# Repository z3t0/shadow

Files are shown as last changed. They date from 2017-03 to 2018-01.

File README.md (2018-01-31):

# SumoDuino 

SumoDuino

### What is this repository for?
**Project Name: SumoDuino**

**Project Summary: AVR based project using to create a SumoBot**

**Version: 1.1**

### Features
* Seek and find navigation system
* Line-Sensing logic to keep robot in the ring
* Several InfraRed sensors to allow accurate seeking

### Credits
Rafi Khan, I am the owner and main contributor to this repository.
Email: zetoslab@gmail.com

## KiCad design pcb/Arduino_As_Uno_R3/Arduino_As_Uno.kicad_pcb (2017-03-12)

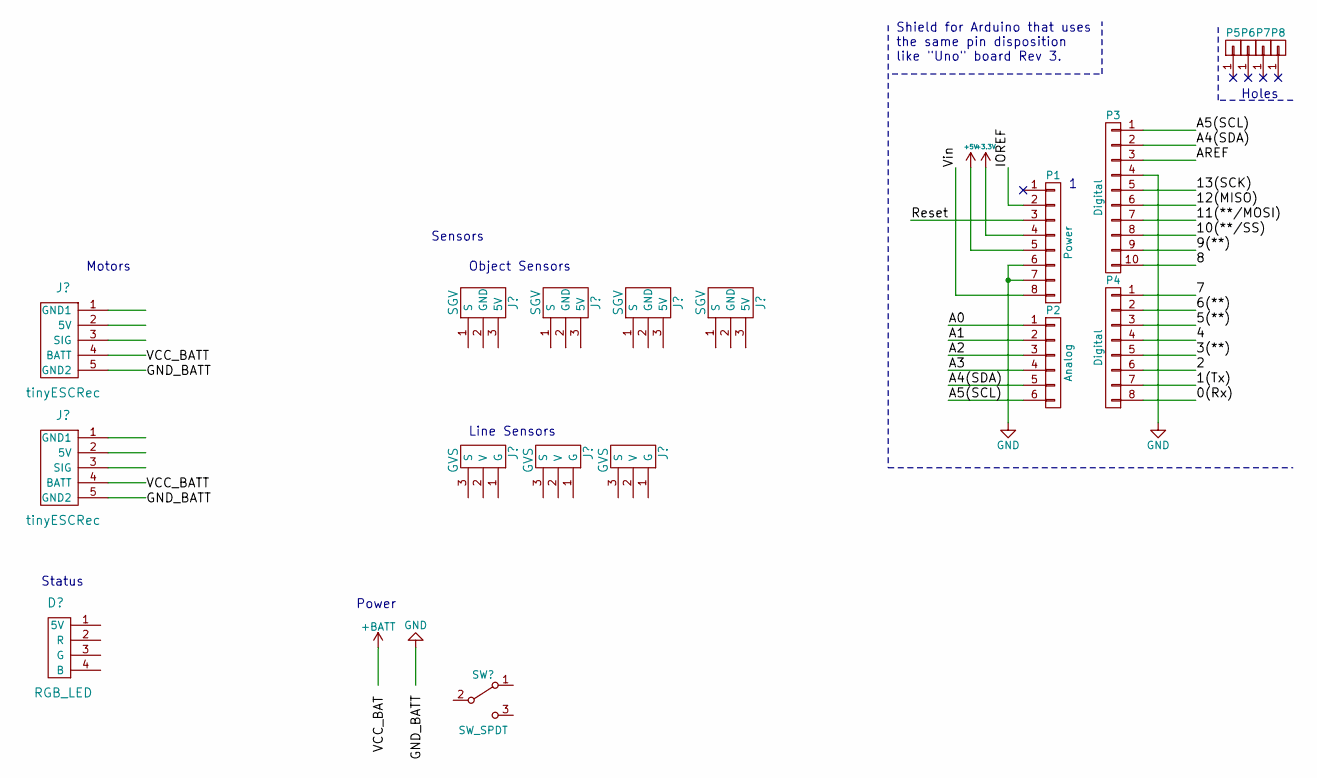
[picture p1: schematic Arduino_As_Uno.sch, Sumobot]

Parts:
P1: Power; Socket_Strip_Arduino_1x08
P2: Analog; Socket_Strip_Arduino_1x06
P3: Digital; Socket_Strip_Arduino_1x10
P4: Digital; Socket_Strip_Arduino_1x08
P5, P6, P7, P8: CONN_01X01; Arduino_1pin

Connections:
+3V3: P1.4
+5V: P1.5
/0(Rx): P4.8
/1(Tx): P4.7
/2: P4.6
/3(**): P4.5
/4: P4.4
/5(**): P4.3
/6(**): P4.2
/7: P4.1
/8: P3.10
/9(**): P3.9
/10(**/SS): P3.8
/11(**/MOSI): P3.7
/12(MISO): P3.6
/13(SCK): P3.5
/A0: P2.1
/A1: P2.2
/A2: P2.3
/A3: P2.4
/A4(SDA): P2.5, P3.2
/A5(SCL): P2.6, P3.1
/AREF: P3.3
/IOREF: P1.2
/Reset: P1.3
/Vin: P1.8
GND: P1.6, P1.7, P3.4

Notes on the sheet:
Holes
Shield for Arduino that uses the same pin disposition like "Uno" board Rev 3.
Sensors
Power
Object Sensors
Line Sensors
Motors
Status

Board: 2 copper layers, 8 parts (0 on the bottom side), 3 nets, no tracks yet.

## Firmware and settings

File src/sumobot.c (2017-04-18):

// sumobot.c
// Copyright (c) 2017 Rafi Khan

#include "sumobot.h"


// On Start
int main() {

    // Setup timers, motors, sensors etc.    
	init();
    // Enable interrupts
    sei();

    while(1) {
      loop();
  }
}


void init() {
#if RELEASE
#endif

#if DEBUG
	initUSART();
	printString("Shadow d\n");
#endif

    prepare_debug_led();
    prepare_ping();
    prepare_line();
    prepare_motor();
    prepare_timer();

    state = START; // beginning state

    _delay_ms(3000); // total 5s delay, 2s for startup

    debug_led(0, 0, 1); // signals that the timer delay is over
}

void loop() {

    switch(state) {

        case START: // spin around and seek the enemy
        set_motor(MOTOR_FWD_HALF, MOTOR_REV_HALF);
        _delay_ms(200);
        state=SPIN;
 
        case SPIN: // seeking the enemy
        // printString("SPIN");
        set_motor(MOTOR_REV_QUARTER +4, MOTOR_FWD_QUARTER - 4);
        debug_led(1, 1, 1);
        printString("SPIN");
        break;

        case RIGHT_LINE: // move back and spin, you've hit the outside on the front right
        debug_led(0, 1, 0);
        break;

        case LEFT_LINE: // move back and spin, you've hit the outside on the front left
        debug_led(0, 1, 0);

        break;
        case FRONT_LINE: // move back and spin, you've hit the outside on both front sensors
        debug_led(0, 1, 0);

        break;
        case BACK_LINE: // charge forwards at full speed, you've been pushed to the edge!
        debug_led(0, 1, 0);

        break;

        case CHARGE_SLOW: // you've been pushing forward for a while, use physics to your advantage by slowing down and increasing friction
        printString("slow");
        set_motor(MOTOR_FWD_QUARTER, MOTOR_FWD_QUARTER);
        break;
    }
}

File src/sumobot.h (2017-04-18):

// sumobot.h
// Copyright (c) 2017 Rafi Khan

#ifndef SUMOBOT_H
#define SUMOBOT_H


// STATE MACHINE
enum STATE {
    DEFAULT,
    START,
    START_DELAY,
    FRONT_LINE,
    SPIN,
    LEFT_LINE,
    BACK_LINE,
    RIGHT_LINE,
    CHARGE_SLOW
};

volatile enum STATE state = START;
volatile enum STATE last_state = DEFAULT;
volatile enum STATE next_state = DEFAULT;
volatile enum STATE timer2_state = DEFAULT;

void set_state(enum STATE s) {
    last_state = state;
    state = s;
    stop_timer();
}

void set_next_state(enum STATE s)  {
    next_state = s;
}

void go_next_state() {
    set_state(next_state);
    // printString("next state");
}
/******************************************************************************
 **** Configuration
 ******************************************************************************/
/// Modifiers
#define DEBUG 1
#define RELEASE 1

/// Constants
#define F_CPU 16000000UL

/// Includes
#include <avr/io.h>
#include <util/delay.h>
#include <avr/interrupt.h>

// Libraries
#if DEBUG
#include "USART.h"
#endif

/******************************************************************************
 **** Program Flow
 ******************************************************************************/
// Forward Declaration
void init();    // Run once at the beginning
void loop();    // Run forever afterwards

/******************************************************************************
 **** Motor Control
 ******************************************************************************/
// PINOUT: Left D5, Right D6
// Timer 0 : OC0B
#define MOTOR_LEFT_BIT PD5

// Timer 2 : OC2A
#define MOTOR_RIGHT_BIT PB3

// TODO: Test motor control
// Set Motors
void setLeftMotor(int pwm);
void setRightMotor(int pwm);

// 1000us : 62.5
// 1500us : 93.75 // 666 Hz
// 2000us: 125

#define MOTOR_FWD_FULL 125
#define MOTOR_FWD_HALF 109
#define MOTOR_FWD_QUARTER 101
#define MOTOR_STOP 93
#define MOTOR_REV_FULL 63
#define MOTOR_REV_QUARTER 86
#define MOTOR_REV_HALF 78

// Sets up motor outputs and timers
void prepare_motor() {
    // TODO: Clean up
    // Start at idle
    OCR0B = MOTOR_STOP;
    OCR0A = MOTOR_STOP;

    DDRD |= _BV(PD5);
    DDRD |= _BV(PD6);
    DDRB |= _BV(PB3);

    // Timer 0 : Left Motor
    // Top : OCR0B. PWM phase correct
    TCCR0B |= _BV(CS02);  // 256 prescaler

    // Phase correct mode, OCRA top
    TCCR0A |= _BV(WGM00) | _BV(WGM01);   // FAST PWM
    // TCCR0A |= _BV(WGM00);
    // TCCR0B |= _BV(WGM02);    
    // TCCR0A |= (_BV(COM0B1) | _BV(COM0B0)); // Inverted?
    TCCR0A |= _BV(COM0B1); // Clear on match
    TCCR0A |= _BV(COM0A1); // Clear on match
}

void left_motor(uint8_t top) {
    OCR0A = top;
}

void right_motor(uint8_t top) {
    OCR0B = top;
}

void stop_motor() {
    right_motor(MOTOR_STOP);
    left_motor(MOTOR_STOP);
}

void set_motor(uint8_t l, uint8_t r) {
    right_motor(r);
    left_motor(l);
}

/******************************************************************************
 **** Line Sensors : QRD1114 with internal pull up
 ******************************************************************************/
/// PINOUT
// Back : D9, PCINT1
#define LINE_BACK_BIT PB1
#define LINE_BACK_PORT PORTB
#define LINE_BACK_DDR DDRB
#define LINE_BACK_PIN PINB

// Left : D2, INT 0
#define LINE_LEFT_BIT PD2
#define LINE_LEFT_PORT PORTD
#define LINE_LEFT_DDR DDRD
#define LINE_LEFT_PIN PIND

// Right : D3, INT 1
#define LINE_RIGHT_BIT PD3
#define LINE_RIGHT_PORT PORTD
#define LINE_RIGHT_DDR DDRD
#define LINE_RIGHT_PIN PIND

/// Prepares Line sensor pins as input and sets up interrupts
void prepare_line() {
    // Set input
    LINE_BACK_DDR &= ~_BV(LINE_BACK_BIT);
    LINE_LEFT_DDR &= ~_BV(LINE_LEFT_BIT);
    LINE_RIGHT_DDR &= ~_BV(LINE_RIGHT_BIT);

    // Enable pullup
    LINE_BACK_PORT |= _BV(LINE_BACK_BIT);
    LINE_LEFT_PORT |= _BV(LINE_LEFT_BIT);
    LINE_RIGHT_PORT |= _BV(LINE_RIGHT_BIT);

    // Interrupts
    //      on LOW for INT0 or INT1
    // EICRA &= ~(_BV(ISC01) | _BV(ISC00) | _BV(ISC10) | _BV(ISC11));
    EICRA &= ~(_BV(ISC00) | _BV(ISC10)); // any logic change
    EIMSK |= (_BV(INT0) | _BV(INT1));     // Turns on INT0 and INT1

    // //      on change for PCINT0
    PCICR |= _BV(PCIE0);
    PCMSK0 |= _BV(PCINT1);  //set PCINT0 to trigger an interrupt on state change
}

// Interrupt called on White for Left
ISR (INT0_vect) {
    if(!(LINE_LEFT_PIN & _BV(LINE_LEFT_BIT)) && !(LINE_RIGHT_PIN & _BV(LINE_RIGHT_BIT))) {
        // FRONT
        set_state(FRONT_LINE);
        set_motor(MOTOR_REV_FULL, MOTOR_REV_FULL);
        set_timer(1000, SPIN); // forward for 500s

    }

    else if (!(LINE_LEFT_PIN & _BV(LINE_LEFT_BIT))) {
        // LEFT
        set_state(LEFT_LINE);
        set_motor(MOTOR_REV_FULL, MOTOR_REV_HALF);
        set_timer(1000, SPIN); // forward for 500s
    }
}

// Interrupt called on white for right
ISR (INT1_vect) {
    if(!(LINE_RIGHT_PIN & _BV(LINE_RIGHT_BIT))) {
        set_state(RIGHT_LINE);

        // set_motor(MOTOR_FWD_HALF, MOTOR_FWD_HALF);
        set_motor(MOTOR_REV_FULL, MOTOR_REV_HALF);
        set_timer(1000, SPIN); // forward for 500s   
    }
}

// Interrupt called for state change on PCINT0
ISR (PCINT0_vect) {
    // TODO: strategy for back
    if (!(LINE_BACK_PIN & _BV(LINE_BACK_BIT))) {
        // Back
        set_state(BACK_LINE);
        // printString("back line");          

        set_motor(MOTOR_FWD_FULL, MOTOR_FWD_FULL);
        set_timer(700, SPIN); // forward for 500s
    }
}

/******************************************************************************
 **** Sonar Sensor : HC-SR04
 ******************************************************************************/
/// PINOUT : Trig D7, Echo D8
#define PING_TRIG_BIT PD7
#define PING_TRIG_PORT PORTD
#define PING_TRIG_DDR DDRD

#define PING_ECHO_BIT PB0 // needed cause ICP1
#define PING_ECHO_DDR DDRB
#define PING_ECHO_PORT PORTB
#define PING_ECHO_PIN PINB

#define PING_MAX_CM 100

volatile uint16_t ref = 0;
volatile uint16_t overflow = 0;

void prepare_ping() {
    // Sensor
    PING_TRIG_DDR |= _BV(PING_TRIG_BIT); //PD7 as output
    PING_TRIG_PORT &= ~_BV(PING_TRIG_BIT); //PD7 to LOW
    PING_ECHO_DDR &= ~_BV(PING_ECHO_BIT); //PB0 as input
    PING_ECHO_PORT &= ~_BV(PING_ECHO_BIT); //PB0 no pullup

    // Timer
    TCNT1 = 0; //Clear TIMER1 value
    OCR1A = 159; // 10 us without prescaler
    TIMSK1 = _BV(OCIE1A); //Enable compare match interrupt
    TCCR1B = _BV(ICES1) | _BV(CS10); // Rising edge, no prescaler
}


ISR(TIMER1_COMPA_vect)
{
    if(PING_TRIG_DDR & _BV(PING_TRIG_BIT)) //Test if query pulse on
    {
        PING_TRIG_DDR &= ~_BV(PING_TRIG_BIT); //End query pulse
        TIMSK1 &= ~_BV(OCIE1A); // disable compare match interrupt
        TIMSK1 |= _BV(ICIE1) | _BV(TOIE1); // Enable input capture interrupt, over flow interrupt
    }
    else //Query pulse not started
    {
        PING_TRIG_DDR |= _BV(PING_TRIG_BIT); //Start query pulse
    }
    TCNT1=0; //Clear TIMER1 value
    // printString("comp");
}
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

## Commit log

2015-02-20 Reorganized code and added PCB files
    [SumoDuino.brd, SumoDuino.sch]
2015-03-06 Many changes, most importantly it is functional and also beta has been merged (OTR). Currently we still need to get navigation tuned but it is functional.
2017-02-06 cleaning up
    [SumoDuino.brd, SumoDuino.sch]
2017-02-26 lots of cad
    [2d.dxf, chassis.scad, top.scad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]
2017-02-26 more designs
    [2d.dxf, clamp_1.stl, mount.stl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]
2017-03-11 clean :
    [2d.dxf, chassis.scad, clamp_1.stl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]
2017-03-11 adding kicad
    [sumobot.kicad_pcb, sumobot.sch]
2017-03-12 manual clone from template
    [Arduino_As_Uno.kicad_pcb, Arduino_As_Uno.sch]
2017-03-17 fixed debug led. it was only setting the ddrx, not the portx
    [sumobot.h]
2017-03-18 added rgb led, added two ir sensors
2017-03-19 working on timers
2017-03-19 reading distance from hc sr04. gave up on ping sensor
2017-03-19 working sensor hc sr04 that is fully based on interrupts
2017-03-20 did a bunch of shit… working sonar, left right line detection. next need to work on motors
2017-03-22 added motor control, working on states. using spark fun board now. other one is fried on vin
